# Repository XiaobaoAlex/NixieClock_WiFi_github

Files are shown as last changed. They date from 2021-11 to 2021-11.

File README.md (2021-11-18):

# NixieClock_WiFi
## 辉光管时钟

### 一、项目概述

&nbsp;&nbsp;&nbsp;&nbsp;&nbsp;&nbsp;&nbsp;&nbsp;功能简述：以飞思卡尔MC9S08DZ60为主控芯片，驱动六个辉光管分别显示时分秒或者年月日，带有wifi模块可以连接互联网正时。

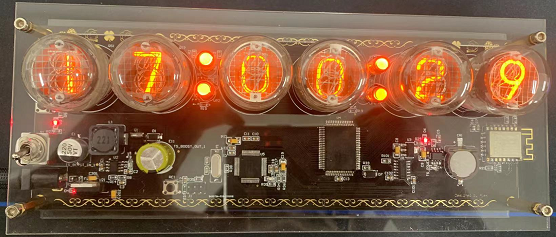
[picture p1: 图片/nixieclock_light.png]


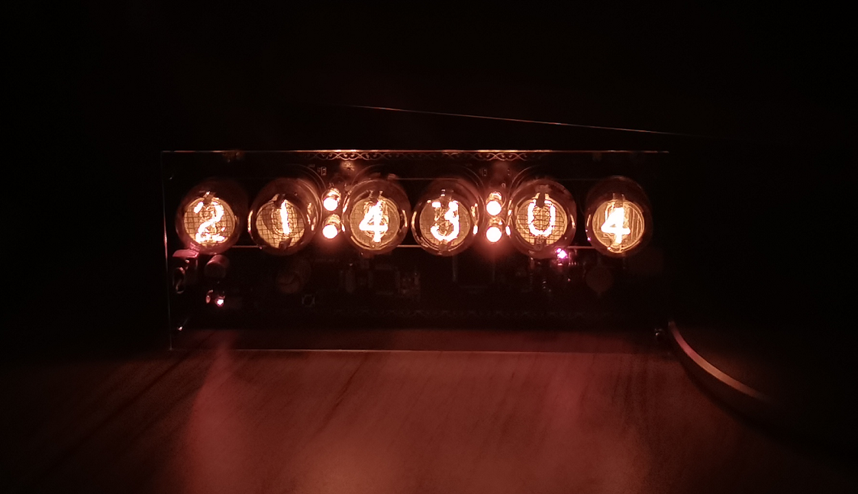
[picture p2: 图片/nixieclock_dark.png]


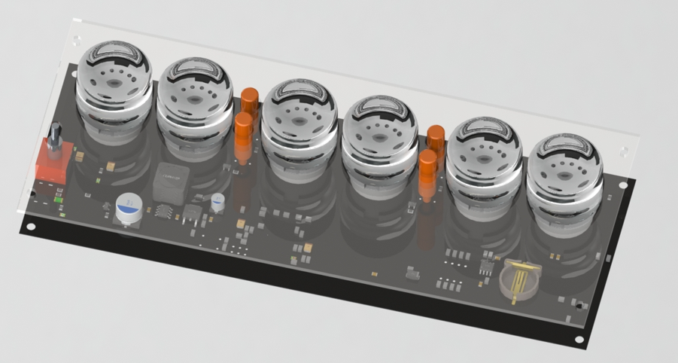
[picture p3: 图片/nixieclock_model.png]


### 二、实现思路

1.板子的最小系统以MC9S08DZ60为核心；

2.辉光管需要170V高压驱动，用MAX1771升压芯片做BOOST升压电路；

3.单片机IO口不足，不能同时控制6个辉光管的60个管脚，用HV57708PG 4路串行输入 64路并行输出芯片做辉光管驱动芯片；

4.使用DS3231实时时钟芯片计时；

5.使用ATK-ESP-01模块连接wifi接入互联网，利用sntp服务正时；

6.电源部分为12V输入，由boost电路将12V转换为170V供辉光管使用,用7805转换为5V作为板子主电源，ds3231和wifi模块的供电均为3.3v,需要电源转换芯片AMS1117-3.3做电源转换；

7.单片机供电电压和工作电压为5V,ds3231和wifi模块与单片机通信要做电平转换，3.3V和5V的电平转换由TXS0104EDR电平转换芯片完成；

8.显示部分由6个国产南昌牌顶显辉光管加4个作为间隔点的氖管组成。

### 三、具体实现

1、MC9S08DZ60最小系统

&nbsp;&nbsp;&nbsp;&nbsp;&nbsp;&nbsp;&nbsp;&nbsp;这个MC9S08DZ60是我们实验室用的芯片，之前也拿它做过毕设，软硬件都搞过，所以得心应手。但是到最后一版的时候，就是我用12V作为供电，用7805转5V给单片机供电之后，最小系统的晶振就是不起振，下不进程序，搞得我又去重新购置了一波元器件来更换最小系统上的电容和晶振，试了还不行。过了一段时间之后，我灵机一动，查了一下7805可不可直接给单片机供电，答案当然是可以，但是输入输出电容那部分就有讲究了。说是要加百uF级别的钽电容滤除低频干扰，nF级别的电容滤去高频干扰。我这按照数据手册上来画的，输出部分就加了100nF的电容，等我换上一个10uF的电容之后，最小系统就正常了。这个电容问题搞得我焊了好几个最小系统，还重新画了最小系统的晶振电路（重新打板），真磨人。

2、max1771升压芯片

&nbsp;&nbsp;&nbsp;&nbsp;&nbsp;&nbsp;&nbsp;&nbsp;关于这个芯片与升压电路真的有很多值得说的。这个电路的原理网上说的非常多，这里只说我设计与制作过程中的经验。

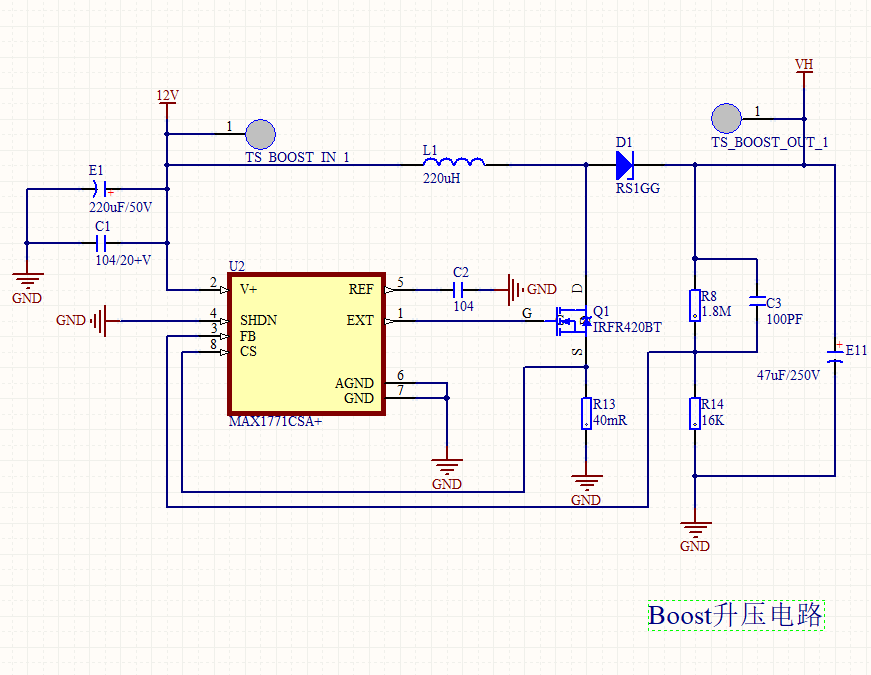
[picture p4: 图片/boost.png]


&nbsp;&nbsp;&nbsp;&nbsp;&nbsp;&nbsp;&nbsp;&nbsp;第一是元器件的选型，不能只想着各个元件的值对了就行，他们的功率也得跟上才行，换句话说他们都得足够大，耐压值大，功率大。这些大了体积自然就大了。我起初就是电感和电容的封装搞错了只能重新打板，当然这只是众多重新打板次数中的一次，E1的耐压值为50V,就是比12V的俩倍还要大，这样才安全。L1为功率电感，体积上去了功率就大，我选的是那种12x12的黑色立方体电感。E11为储能电容，输出电压为170V,所以耐压值得选250V.我选的是插针电解电容。还有就是MOS管Q1的耐压值也得大，要超过170V,我起初用的是数据手册上推荐的，但是我没注意到它是低压的mos管，结果电路不工作。D1得选快速开关的肖特基二极管。注意看的我这几个元件是不是都特别大，哈哈哈。

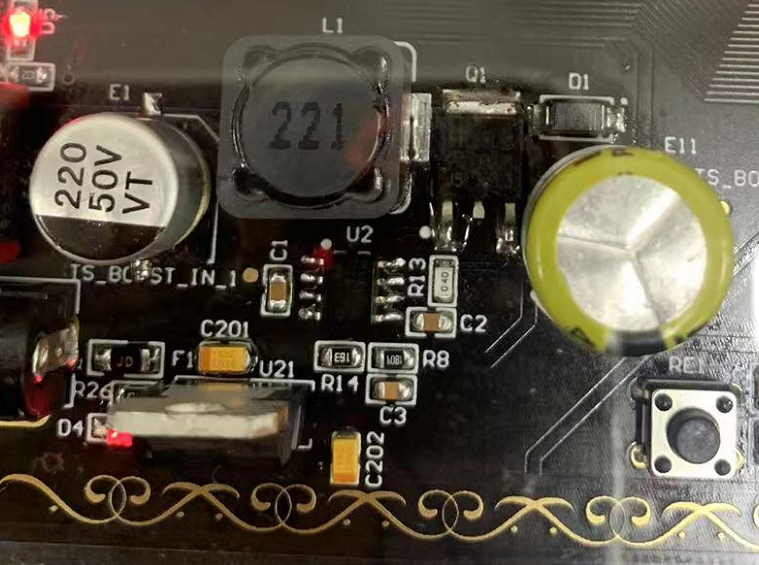
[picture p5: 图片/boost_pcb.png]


&nbsp;&nbsp;&nbsp;&nbsp;&nbsp;&nbsp;&nbsp;&nbsp;第二是升压部分。这个BOOST升压电路按我的理解就是开关电源，主要靠R8和R14来控制升压比，按数据手册上给的公式来看，理论上电压升到任何高度都可以，但是注意，电压肯定是不能升高到无穷大的，换句话说，我们要注意输入电压的大小。我们需要一个170V的高压辉光管才能正常工作，那我们应该用多大的电压作为输入呢。实践证明，5V是不行的，我起初是用5V做的输入电压，想着用type-c接口为板子供电，这样电路在空载的时候输出很不错，稳稳的170V,到这我就以为我的升压电路做好了，可是到最后同时驱动6个管子的时候，电压直线下降，加上6个管子之后升压电路输出只有122-125V,六个辉光管亮是亮了，但是缺笔画现象严重，有的管子甚至不亮，根本不能用。中间还以为我选的电感有问题，疯狂研究这个升压电路，最后换了那种5.5mm-12V圆形接口才成功（第二次打板）。网上虽然大多是用12V作为输入的，但是他们也没说5V不行啊啊啊啊。

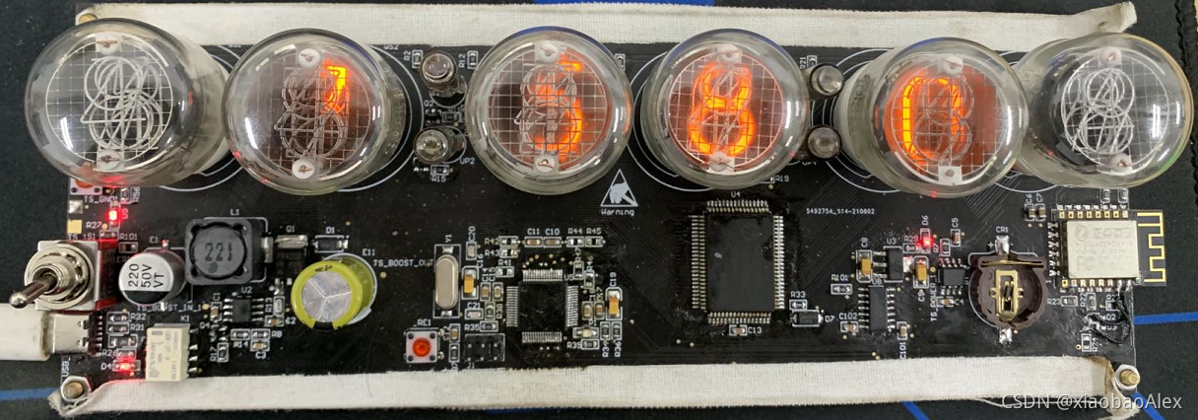
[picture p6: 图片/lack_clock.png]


3、ATK-ESP-01模块

硬件部分

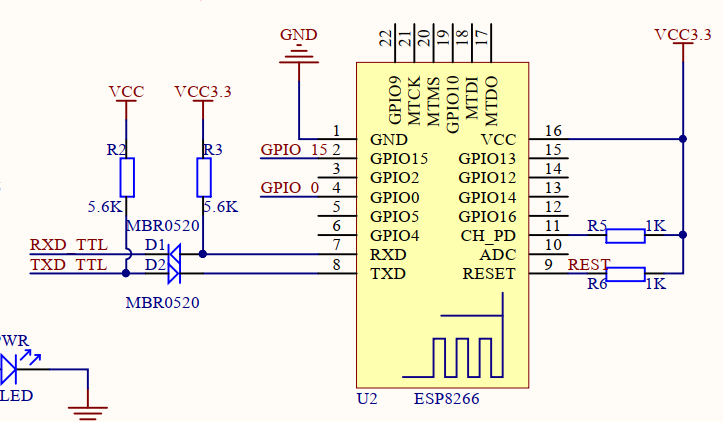
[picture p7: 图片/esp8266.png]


&nbsp;&nbsp;&nbsp;&nbsp;&nbsp;&nbsp;&nbsp;&nbsp;TX、RX需要和单片机叉接。它这个原理图就非常的まよい，这俩个上拉电阻和二极管给我整懵了，搞得我以为D1那条线是TX,D2那条线是RX.当然到最后我理解这个原理图的深意，其实他是对的。（当TXD输出1，二极管截至，TXD_TTL被拉高，也是1；当TXD输出0，二极管导通，TXD_TTL和TXD电平相等，也是0。）最后我是没要这俩个上拉电阻和二极管，直接连的电平转换芯片，它内部已经被上拉了的。

软件驱动部分

&nbsp;&nbsp;&nbsp;&nbsp;&nbsp;&nbsp;&nbsp;&nbsp;直接用AT指令驱动，需要注意的是，它的默认波特率为115200，需要操作一下把波特率改为9600方便后来操作；另外调试这个模块一定一定要搞串口调试器和逻辑分析仪，先用串口调试器和串口调试助手发送指令看看能不能连接无线网，测试模块的功能是否正常，之后用单片机收发指令的时候需要逻辑分析仪看所有信息的发送接收情况，这样你就能知道问题到底出在哪里。
在连上路由之后需要设置时区，注意，发送连接wifi指令之后大概4-5s模块才能真正连接路由，这个时候才能设置时区，所以在发送连接wifi命令后要设置比较长的延时，不然返回的时间就是1970年00时00分00秒。
那么接收时间字符串之后如何把时间信息取出。主要用memcpy和strstr函数解决，用memcpy函数将固定区域的字符串取出就可以得到年月日时分秒星期，对于月份和星期，他们是字母表示的，得用strstr函数判别，如果找到对应字符串就能确定是月份和星期。具体代码请查看我的开源项目链接，不拿出来说啦。

4、DS3231实时时钟芯片

&nbsp;&nbsp;&nbsp;&nbsp;&nbsp;&nbsp;&nbsp;&nbsp;DS3231是一款高精度I2C实时时钟器件，具有集成的温度补偿晶体振荡器。该器件包含电池输入端，断开主电源时仍可保持精确计时。集成的晶体振荡器可提高器件的长期精确度。芯片封装使用SOP-8封装，且几乎不需要外部器件支持，使用IIC协议和主控芯片通信。为了达到主要电路调电依旧可以完成走时的功能，使用3.7V CR1220 纽扣电池和电池座为DS3231MZ芯片提供备用电源，使芯片在外部供电中断时依旧可以走时。
这个软件驱动部分主要就是看网上的驱动代码，遇到问题就啃数据手册。

5、HV57708高压驱动芯片
这个芯片很有意思，起初我是没有看数据手册就是抄网上的驱动代码，结果发现驱动不了，就只得自己啃数据手册。

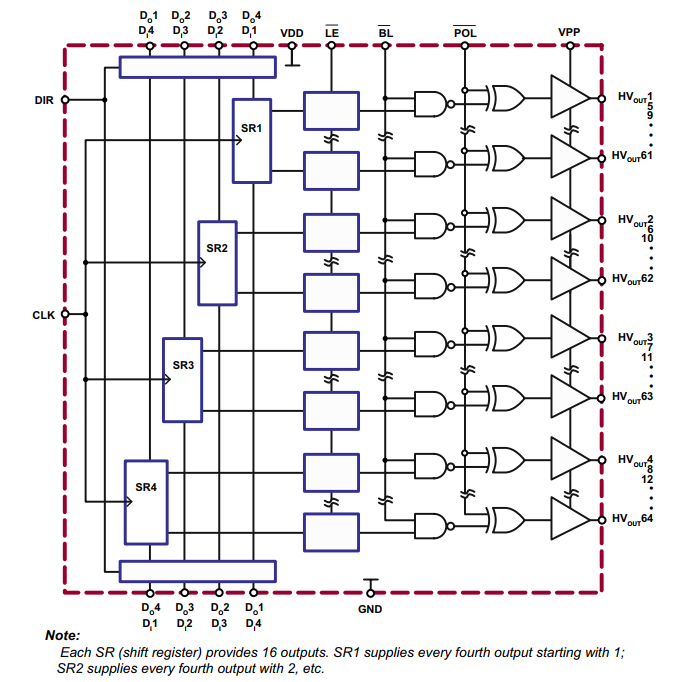
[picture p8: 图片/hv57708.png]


&nbsp;&nbsp;&nbsp;&nbsp;&nbsp;&nbsp;&nbsp;&nbsp;如上图所示，这里的POL是控制标准模式输出或反向模式输出的，驱动的辉光管亮灭的方法，是在所有数字阳极一个170V的高压，在某个数字阴极给68V，两端电压只有100多伏，电压不够该数字灭，反之给0V使数字亮。这种高电压灭低电压亮，就是反向输出模式。VPP上给68V电压，输出的高电压由此而来，它是靠稳压二极管把170V降压得来的.LE上有个取反符号，在写时序时要特别注意。
HV57708是一款可以承受高电压的串行输入转并行输出的驱动芯片，可完成4路输入转64路输出的功能。SR1、SR2、SR3、SR4都是16位寄存器，每个寄存器往右边控制16个管脚的高低压输出，他们加起来也就可以同时控制64个高低压输出。前提是要牺牲一定时间来写满这4个16位寄存器，那么如何写呢，我们注意看图，首先这四个寄存器与管脚不是一一对应的，如图SR1对应的管脚就是1、5、9、13…,这样设计主要是方便我们写入。要输入一个64位的值，这样的数据类型太大了，所以我们将其分开来放在俩个32位数据里，命名为datapart1、datapart2，首先按照Di4、Di3、Di2、Di1的顺序，将后一个32位的数据datapart2的后四位，写入这4个16位寄存器SR4、SR3、SR2、SR1的第一位值（从上面的Di4、Di3、Di2、Di1写，用DIR可以控制写入方向），也就是写好了64、63、62、61这个四个端口，看！这样是不是就正好对上了，我要输入数据的最后四位就对上了这个芯片的最后四位。之后依此类推，再次写入15次，这64位寄存器就全写好了，缺点就是牺牲了时间，但是这个芯片的时序非常快，大家不用担心，驱动秒级别的时钟根本没问题。当时看懂这个芯片还挺开心的，觉得非常有意思。真，不懂就得看数据手册，网上的信息很混乱，但是数据手册永远不会骗你。

6、辉光管与电路板总体布局

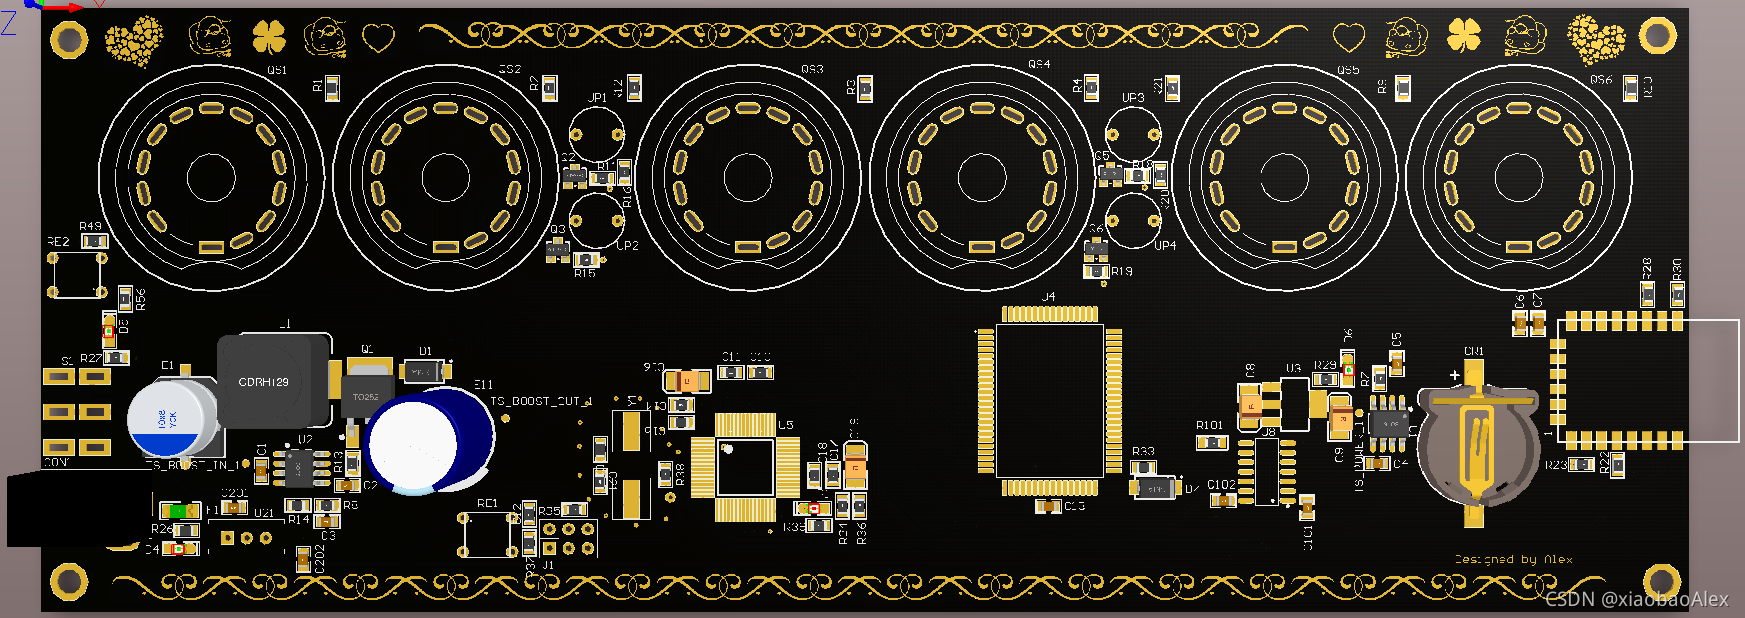
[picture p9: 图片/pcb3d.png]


&nbsp;&nbsp;&nbsp;&nbsp;&nbsp;&nbsp;&nbsp;&nbsp;六个辉光管分别显示时分秒，中间由氖管作为分隔符隔开。板子采用沉金工艺，上面的图案作装饰用 ，别忘了这是做给女朋友的礼物，哈哈哈。为了找这个花边的图案我花了好长时间，处理这个花边的时候因为画图自动的二值化效果太差了，我还用了matlab进行二值化，真的是走心的。

7、壳体

&nbsp;&nbsp;&nbsp;&nbsp;&nbsp;&nbsp;&nbsp;&nbsp;亚克力板1.9毫米无色高透明材质，CAD绘制好找淘宝加工，4块板11块钱，挺好不贵。

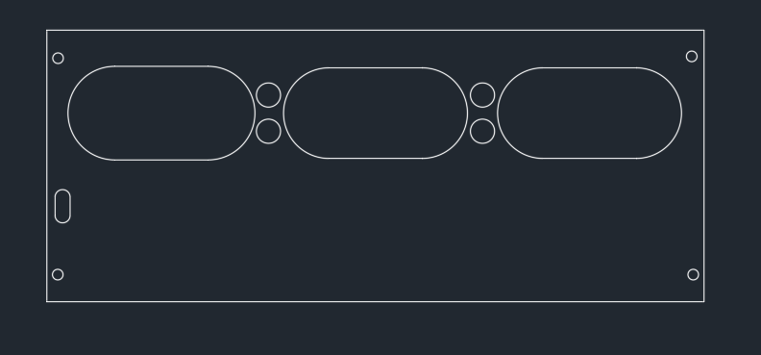
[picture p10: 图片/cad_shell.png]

9、软件架构

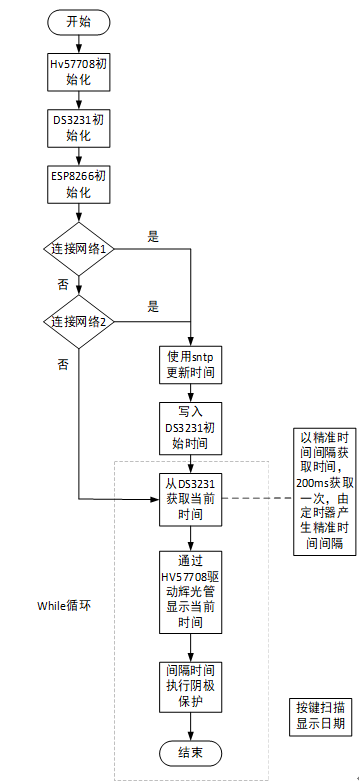
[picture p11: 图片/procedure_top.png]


### 四、总结与心得体会

&nbsp;&nbsp;&nbsp;&nbsp;&nbsp;&nbsp;&nbsp;&nbsp;这个项目最开始的电路原理图、电路板和程序搞的特别快，毕竟网上有很多资料可以参考，电路照着画再稍微根据自己的实际情况修改一下，程序拿别人的驱动再结合自己单片机修改一下，最初的电路板和程序搞的比较快，但是这时候电路板和程序都不知道好不好使，电路板只是自己认为没有问题，程序只是编译通过不报错。接下来就是漫长曲折的调试环节，中间遇到了各种问题，踩了很多坑，可以说该踩的坑都踩了。回想起来，前期绘制了3维模型并作了渲染，打板回来后就一直进行软硬件调试，遇到问题的时候请教了很多朋友，老师；各种论坛看各种帖子也请教了不少博主；下载了很多别人的项目来参考；使用各种调试工具来辅助调试；改了很多最初的设计，在嘉立创打了4次样板。可以说这是一个站在前人的肩膀上，不断思考不断尝试不断修正的过程，最终完成了这个项目。

&nbsp;&nbsp;&nbsp;&nbsp;&nbsp;&nbsp;&nbsp;&nbsp;好了，完结撒花。

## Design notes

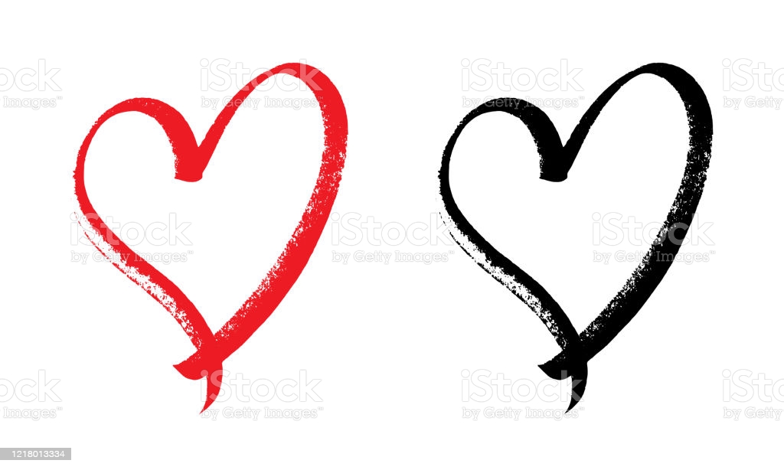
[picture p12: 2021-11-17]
图片/istockphoto-1218013334-1024x1024.jpg

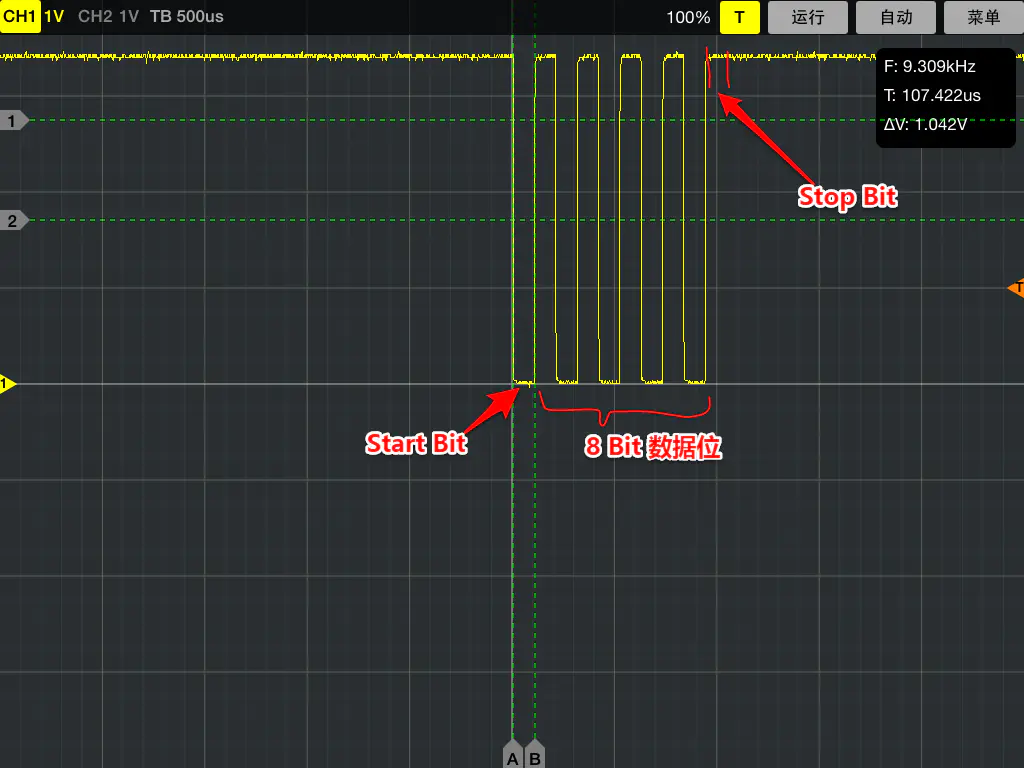
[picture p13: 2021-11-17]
图片/ee204bfbc8d77fdf14ca48ce8faf381a.png

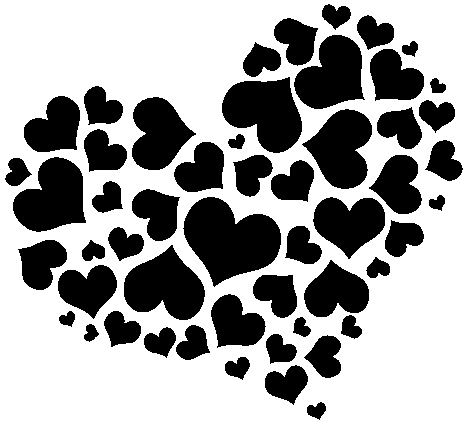
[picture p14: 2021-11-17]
图片/xinxin.bmp

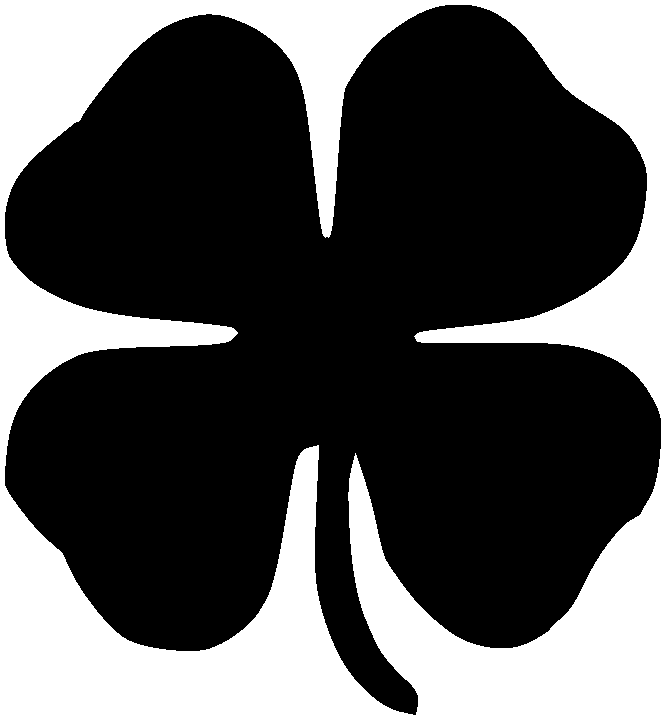
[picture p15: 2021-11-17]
图片/四叶草.bmp

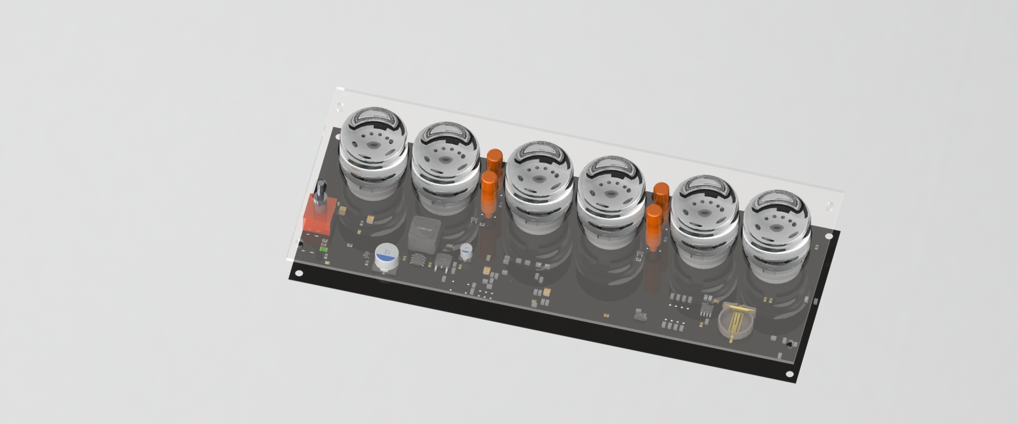
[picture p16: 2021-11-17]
亚克力面板/渲染效果图4.JPG

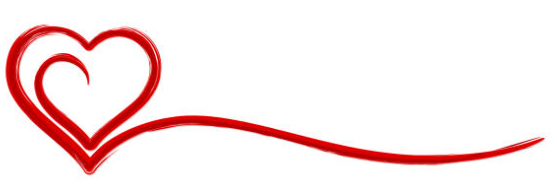
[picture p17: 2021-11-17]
图片/微信截图_20210717144555.png

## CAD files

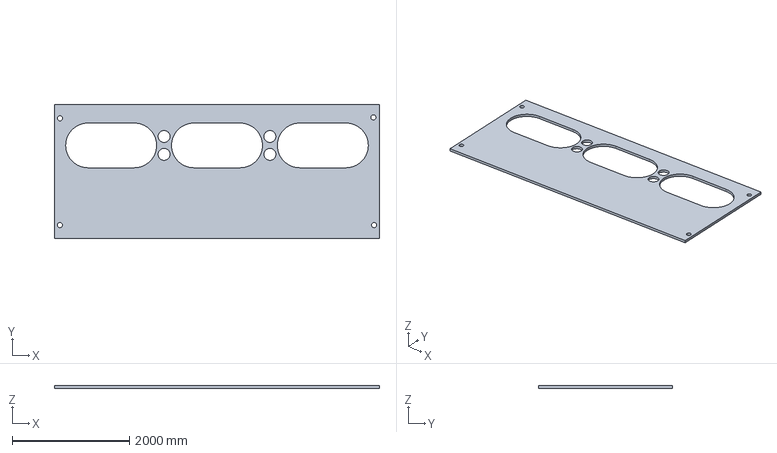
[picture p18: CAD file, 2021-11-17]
亚克力面板/step/top_panel4.stp
5537.2 x 2286.0 x 48.3 mm

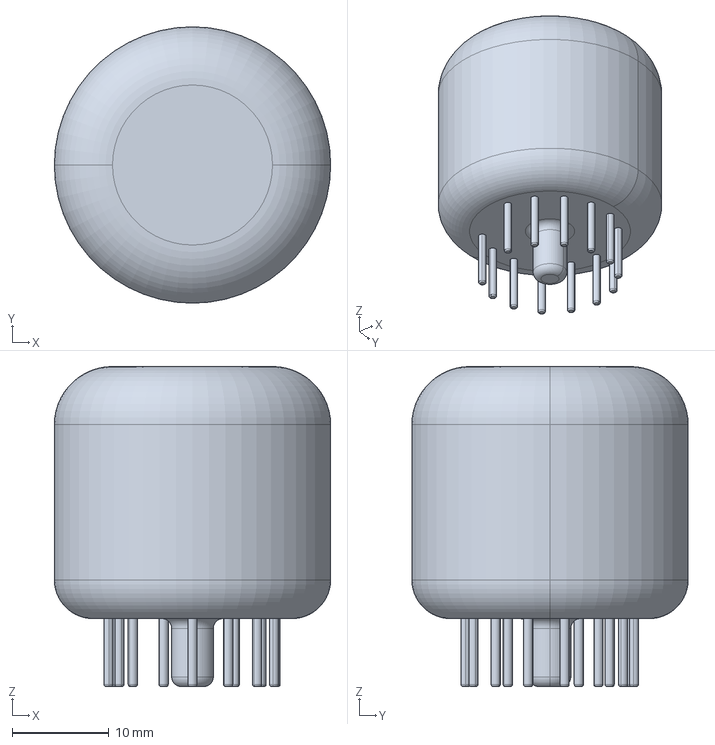
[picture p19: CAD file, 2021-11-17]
亚克力面板/step/nixie_tube.stp
28.5 x 28.5 x 33.0 mm

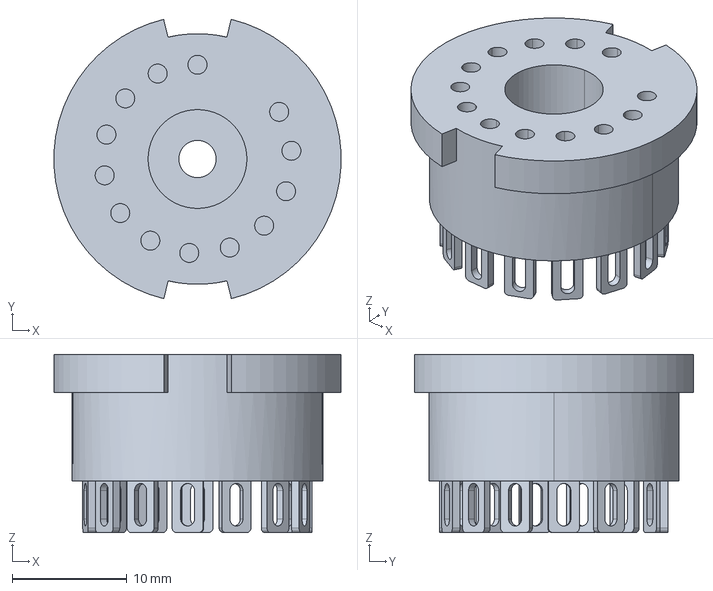
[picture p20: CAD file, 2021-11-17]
亚克力面板/step/tube_socket.stp
25.0 x 24.3 x 15.5 mm

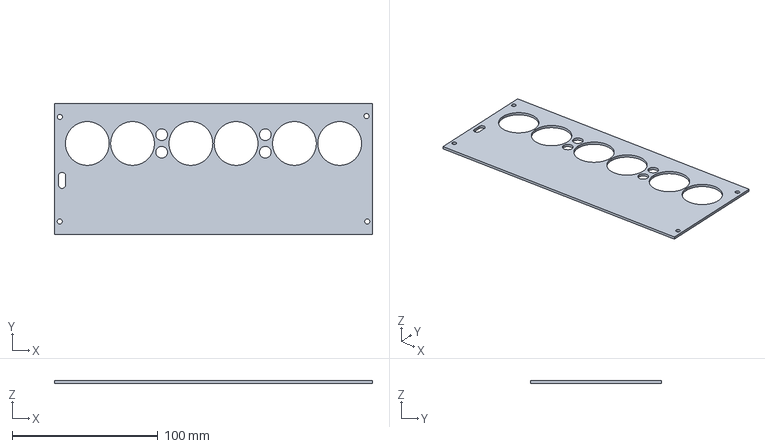
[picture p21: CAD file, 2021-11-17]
亚克力面板/step/top_panel3.stp
218.0 x 90.0 x 1.90 mm

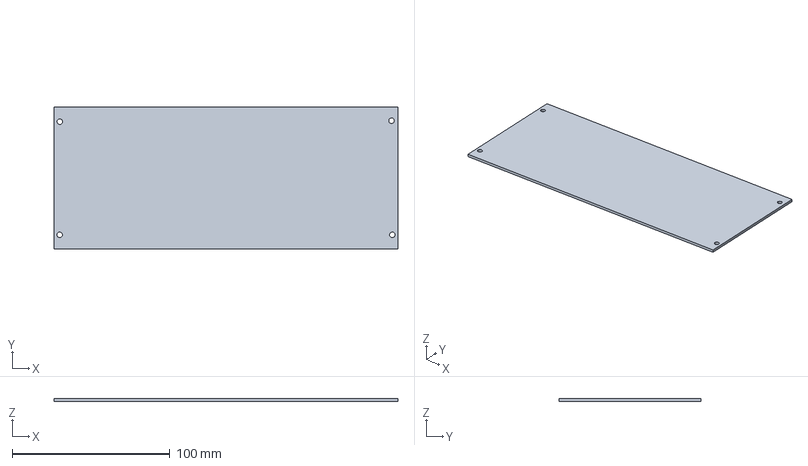
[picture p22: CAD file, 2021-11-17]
亚克力面板/step/bottom_panel.stp
218.0 x 90.0 x 1.90 mm

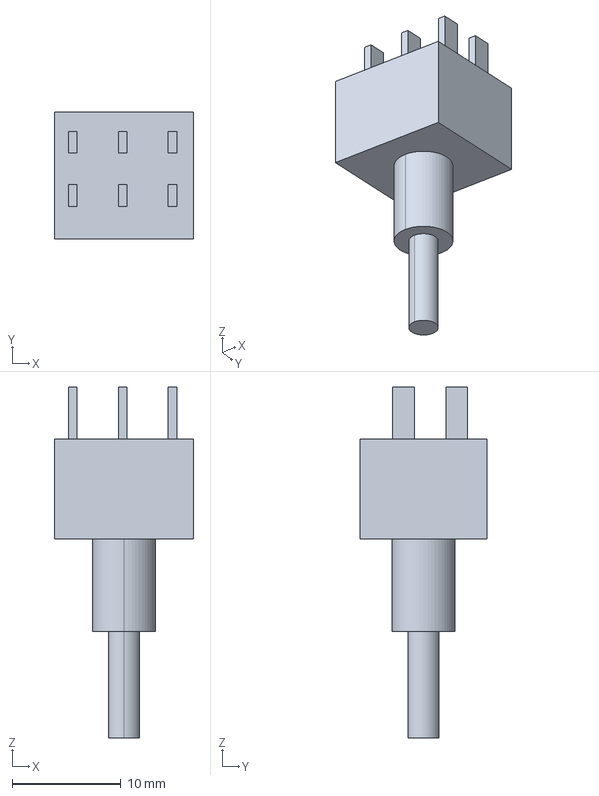
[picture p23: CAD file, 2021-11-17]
亚克力面板/step/toggle_switch.stp
12.8 x 11.7 x 32.4 mm

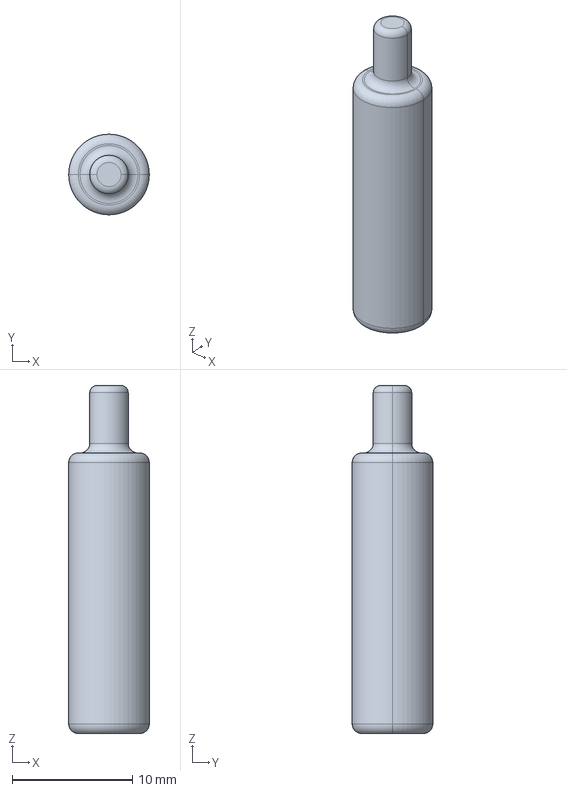
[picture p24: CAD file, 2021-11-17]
亚克力面板/step/neon.stp
6.70 x 6.70 x 28.9 mm

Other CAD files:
Hard_work/nixie_clock.DWG
亚克力面板/上面板第二版/top_panel.dwg
亚克力面板/dwg/bottom_panel.dwg
亚克力面板/dwg/top_panel.dwg

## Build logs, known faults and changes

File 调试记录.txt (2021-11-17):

先看资料

原理图已绘制完成

元器件已购买

pcb已初步布局

接下来进行精细布局，确定辉光管、氖管封装大小及位置，底板大小并建立三维模型，用solidworks绘制亚克力板模型

60x215较小，四周没有放置图案花纹的地方。打算扩大至75x230

电路板已发去打板

软件已编好

开始绘制3维模型

3维模型已画好

面板发去加工

升压电路焊接完毕，无法正常工作，查看数据手册发现mtd20N03hdl

mosDS之间的耐压值不够大，当初选这个是因为数据手册上的典型应用是这个，但是它那个是12V,5V低压输出，可以用这个低压mos管

试图更换MOS管IRFR420BTM

注重在制作过程中的拍照记录

贴片发光二极管有颜色的那一头为正

调试记录：

1、单片机是可以正常运行的，可使状态指示灯按照程序点亮熄灭

2、继电器应该是好使的，但闭合和断开时对应的升压电路的值为0和4.4V,考虑是继电器能通过的最大电流的值不够。

3、不应该是继电器能通过的最大电流的值不够这个原因。

4、辉光管驱动芯片VPP引脚处的稳压二极管稳压范围不够，已冒烟烧毁，可能是这个原因导致升压电路不能输出正常电压，寻找大电压范围的稳压管

5、经查数据手册和检查电路，发现稳压二极管焊反，而且稳压二极管的稳压值是对的，HV57708的VPP就是在90V之下。

6、稳压二极管调整之后稳压在70V,但是其他地方的170V也被稳在 了70V.

7、软件中，和esp8266进行串口通信存在问题，无法接收数据

8、单片机串口电平为5v,ESP8266串口电平为3.3V，二者不能直接相连。在网上看了许多解决办法，有的说兼容，有的说串联200欧电阻，有的说有三极管做个简单的转换电路，有的说用电平转换芯片，决定上电平转换芯片重新制版

9、esp8266的灯不是很亮

10、去点稳压管和限流电阻之后电压回到了170V,但是纹波很大

11、氖管的大圆筒接负极

12、画完板之后用串口调试助手试试wifi模块

~~13、升压电路准备俩个电容位焊接电容~~

14、留出方形焊盘电源输入接口供可调电源输入以显示消耗电流

15、升压电路注意布局

16、去掉拨码开关改加按键在左侧

17、更改RS1G封装、继电器封装、

18、3.3V降压芯片放在右边离芯片近处，给时钟和wifi芯片更好的供电

19、由于240k限流电阻的焊盘太小了，导致虚焊或者错位，又或者印制电路板的原因，电阻焊上之后阻值莫名的小，只有53欧，然后就导致升压电路提供电流能力不足，只能被拉到70V,至此问题已清晰明朗。

20、把升压电路输出电容换大电压会稳很多

21、把所有小规格焊盘全部替换掉。

22、下次生成gerber文件记得过孔盖油

23、焊完电源焊最小系统板，不然真的不知道最小系统板为什么不能正常运行

24、板子焊完后发现单片机不能下载进程序，硬件电路重焊过后还是不好使，目前不能找出原因

25、已重新焊了最小系统，测试了可以正常运行，打算在这个板子上继续焊接

26、稳压二极管俩端电压还是有问题，稳在了10V以内的电压，但是升压电路输出的电压正常，限流电阻测出的阻值极大，这可能是稳压不正常的原因

27、串口通信注意TX,RX不要接错

28、波特率不一致但接近可能也会出现通信不成功的情况，减小波特率并缩小两者波特率之差可能会成功

29、esp8266模块出现发送指令之后，先返回发送的指令字符然后在返回应答字符，已购买逻辑分析仪等待进行下一步试验。示波器虽然也能实现逻辑分析仪的功能但还是比较费劲

30、逻辑分析仪非常好用，已解决wifi模块问题，上述现象是wifi模块的回显模式造成的，关闭即可

31、hv57708驱动已编写完成并验证测试成功。编写驱动需充分理解数据手册，不然不能理解别人程序是意思，虽然能借鉴但肯定不能完全适配自己项目的情况

32、这些管子由于生产年限久远加上当年生产技术的关系，完美程度不高，常见的一个通病就是显示笔段不完全，尤其是在标准供电电压下，很多的南昌牌与宇宙牌的管子显示亮度很差，很多笔画多处显示不全，这个问题在最初开发的时候搞的非常头痛。后来经过实际测试，找到的解决方法也比较简单，那就是提高驱动电压与降低限流电阻。通过实际的测试发现，只要不是老化非常严重的管子，一般驱动电压提高到200～250V左右，限流电阻阻值降低２０％～３０％左右时，大部分的管子都可以确保正常的显示亮度。极个别的管子如果依旧有个别的字符显示不全，则可尝试进行活化修复处理。

33、换成2.2M欧电阻过后电压变成了122-125V之间

34、换成1.8M欧电阻过后电压加6个管子变成了122-125V之间

35、换成1.8M欧电阻过后电压加2个管子变成了147-148V之间

36、换成1.8M欧电阻过后电压加1个管子变成了160-164V之间

37、稳压管的电压容易在运行一段时间后变为4V

38、空载电流在80mA-140mA

39、加上一个管子电流在150到200mA

40、把电感值加大，换成330uH后加两个管子变成130V左右,还是不行（听师兄说带载能力不够应该换小感值）

41、准备重新制版，电源换成12V，5v稳压换7805，去掉继电器，去掉hv57708上拉电阻,去掉WiFi模块电阻和二极管，去掉usb,添加12v接口，过孔盖油



42、板子已改好发去嘉立创加工

43、板子已到准备焊接

44、新板电源纹波在159mV和239mV之间跳动，晶振不起振。

45、老板电源纹波和新版差不多，但是晶振起振，在晶振下方测量会出现良好正弦波形，频率为4Mhz

46、晶振两边的电压2.4V（正弦输出端）和1.1V，焊了最小系统，也不行。

47、换了2.2M欧的RF,晶振两边的电压3.0V（正弦输出端）和1.6V

48、第四版已发去加工，改进了晶振PCB布局

49、第四版最小系统已焊接，晶振俩端的电压为0.1v左右，正常的晶振俩端电压为2.2-2.3V.准备换一批元器件试试

50、已从电子大世界重新采购一批元器件，准备焊接测试

51、今天下午再焊一版试试，不行重新修改

52、下午焊的新版成功运行程序，在7805的输出端加了10uf的电容

53、弄清楚c语言双引号和单引号的区别，双引号会自动在字符串的末尾加上'\0'，单引号不会，而c语言函数库正是使用这个来判断该字符串是否结束，否则程序可能跑异常。

54、时钟初始化时向小时寄存器写0，导致时钟芯片在不连接互联网正时时小时位寄存器为0.

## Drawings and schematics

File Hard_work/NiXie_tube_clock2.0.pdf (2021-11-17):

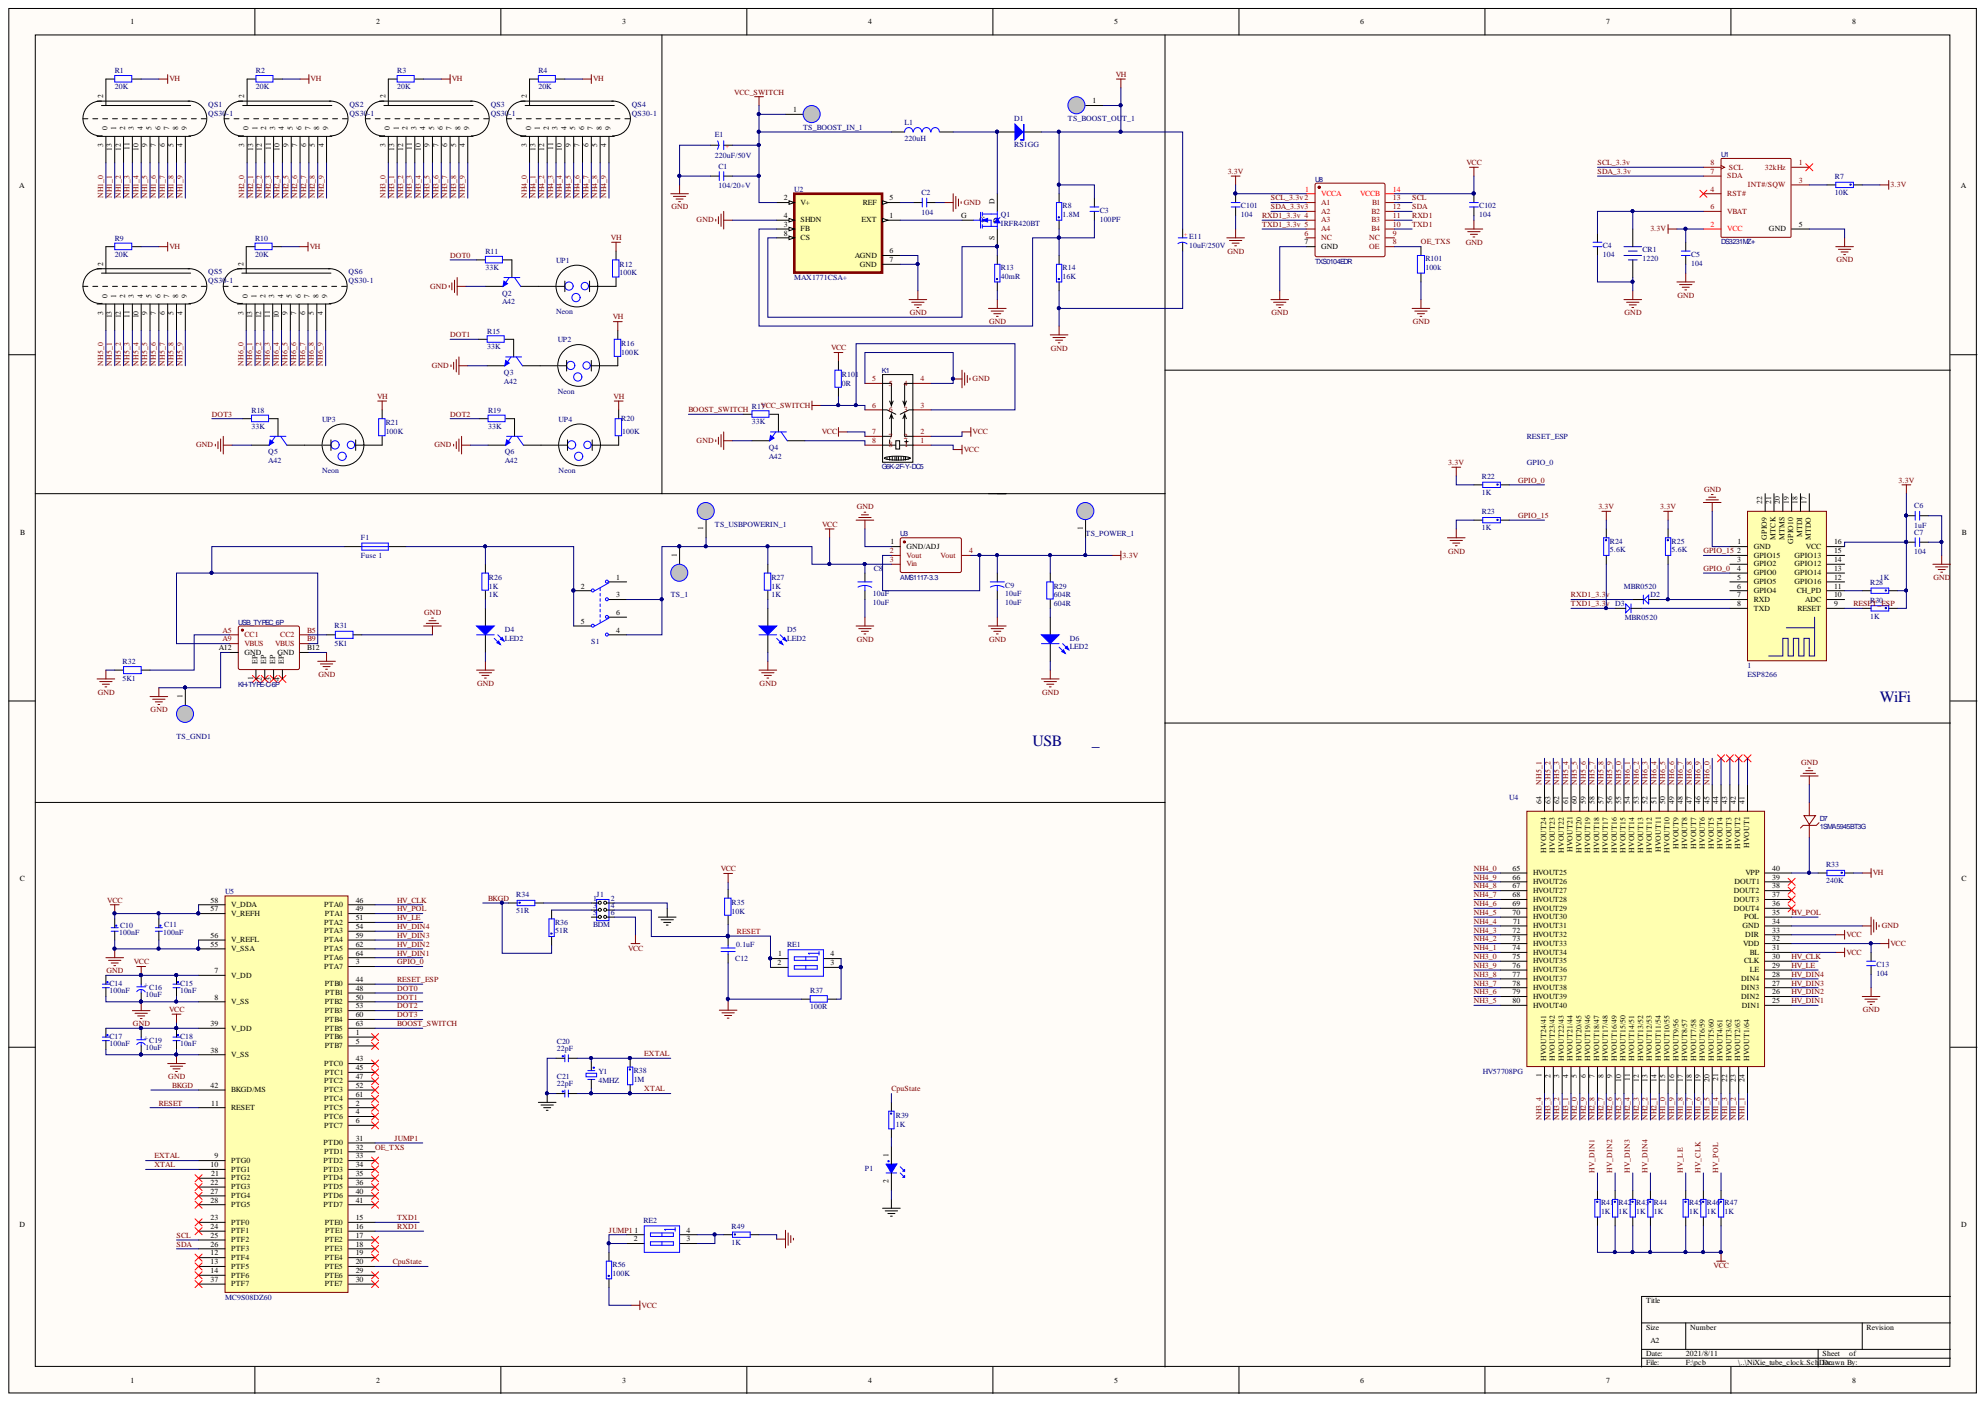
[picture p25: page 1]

HVOUT1/64 24 DIN1 25 DIN2 26 DIN3 27 DIN4 28 LE 29 CLK 30 BL 31 VDD 32 DIR 33 GND 34 POL 35 DOUT4 36 DOUT3 37 DOUT2 38 DOUT1 39 VPP 40

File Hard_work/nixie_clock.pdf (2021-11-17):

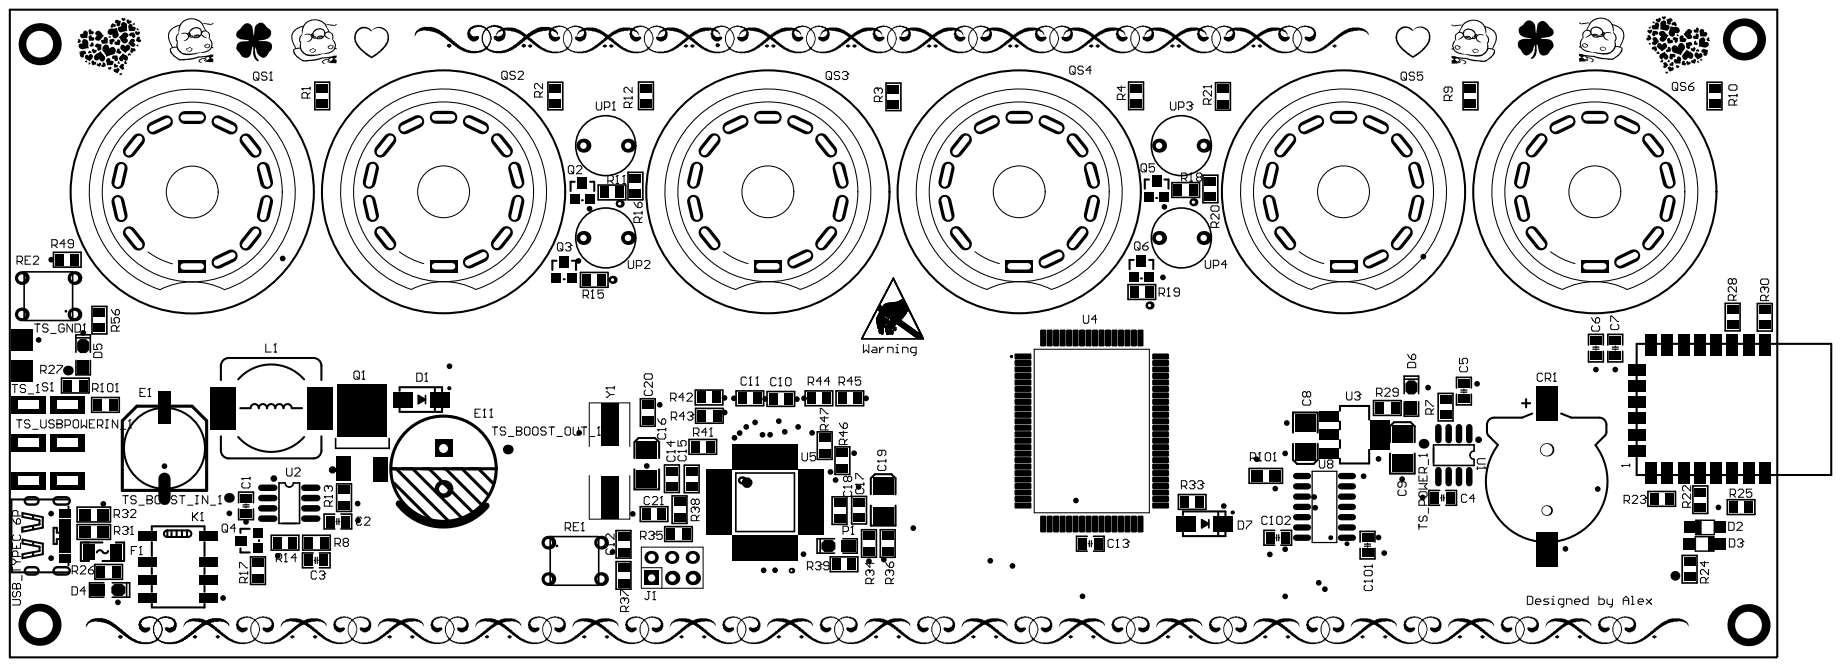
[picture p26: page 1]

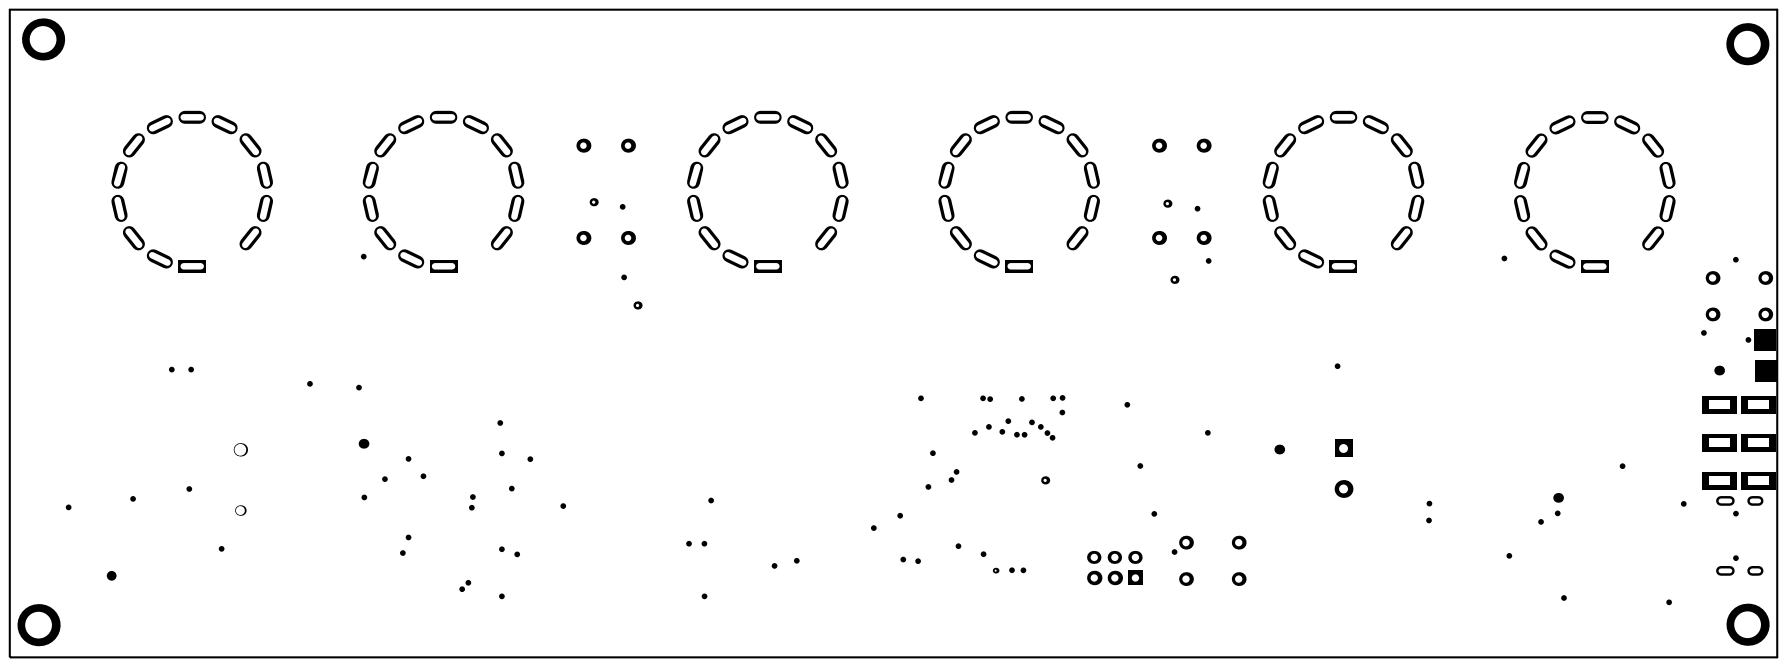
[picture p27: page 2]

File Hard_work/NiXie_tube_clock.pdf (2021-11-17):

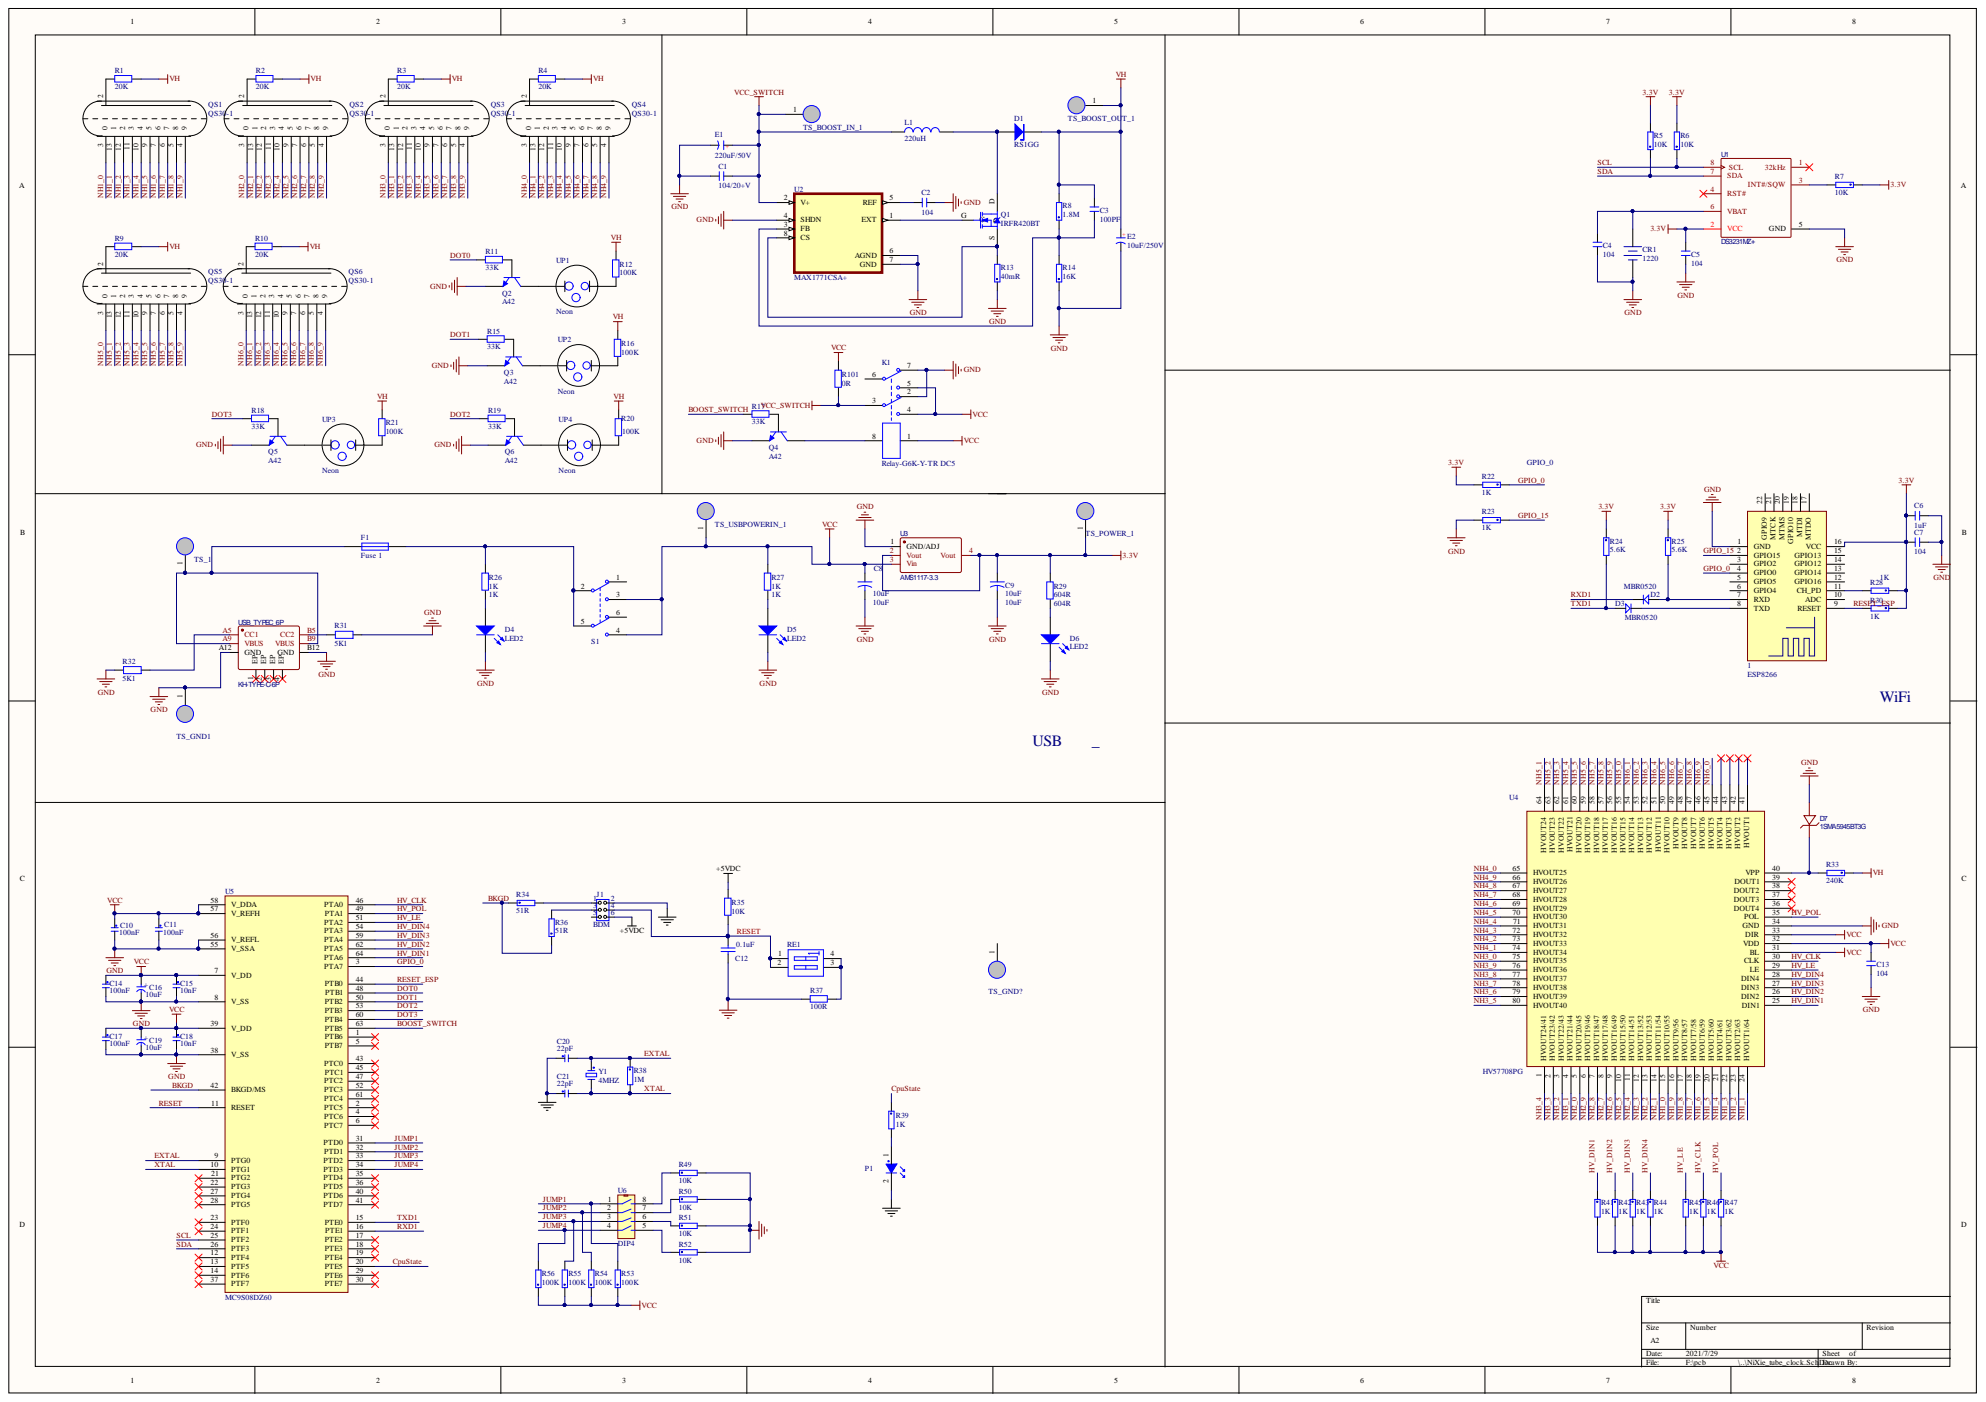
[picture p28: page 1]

MTDO 17 MTDI 18 GPIO10 19 MTMS 20 MTCK 21 GPIO9 22

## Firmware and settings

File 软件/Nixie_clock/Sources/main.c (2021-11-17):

#include <hidef.h> /* for EnableInterrupts macro */
#include "derivative.h" /* include peripheral declarations */
#include "HV57708.h"
#include "PinDef.h"
#include "delay.h"
#include "ds3231.h"
#include "esp8266.h"
#include "usart.h"
#include "stdio.h"
#include "string.h"


unsigned int Flag_Collect;//周期采集时间标志
#define RTC_1_MS        1
#define RTC_10_MS       10
#define RTC_100_MS      100
#define RTC_200_MS      200
#define RTC_1000_SEC    1000//RTC模数寄存器
#define LED	PTED_PTED5
#define LED_D	PTEDD_PTEDD5

struct time timearray;
unsigned char set[7]={0,0,0,0,0,0,0};
unsigned char cmd[4]={"AT\r\n"};//数组长度必须与实际指令字符长度一致
unsigned char close_echo[6]={"ATE0\r\n"};
unsigned char cmd_MODE[13]={"AT+CWMODE=1\r\n"};
unsigned char cmd_WIFI[29]={"AT+CWJAP=\"2205\",\"82568316+\"\r\n"};
unsigned char cmd_WIFI1[33]={"AT+CWJAP=\"CMCC-A35C\",\"6a3aJGbc\"\r\n"};
unsigned char cmd_TimeZone[36]={"AT+CIPSNTPCFG=1,8,\"ntp.aliyun.com\"\r\n"};
unsigned char cmd_Time[17]={"AT+CIPSNTPTIME?\r\n"};
unsigned char reback_Time[60]={'0','0','0','0','0','0','0','0','0','0',\
								'0','0','0','0','0','0','0','0','0','0',\
								'0','0','0','0','0','0','0','0','0','0',\
								'0','0','0','0','0','0','0','0','0','0',\
								'0','0','0','0','0','0','0','0','0','0',\
								'0','0','0','0','0','0','0','0','0','0'};
char reback_WIFI[20]={'0','0','0','0','0','0','0','0','0','0',\
'0','0','0','0','0','0','0','0','0','\0'};
char reback_WIFI1[20]={'0','0','0','0','0','0','0','0','0','0',\
'0','0','0','0','0','0','0','0','0','\0'};
unsigned char reback_WIFI_DISCONNECT[20]={'0','0','0','0','0','0','0','0','0','0',\
'0','0','0','0','0','0','0','0','0','0'};
unsigned char reback_WIFI_GOT_IP[20]={'0','0','0','0','0','0','0','0','0','0',\
'0','0','0','0','0','0','0','0','0','0'};
char result[14]={"CONNECTED"};
unsigned char result_dis[10]={"DISCONNECT"};
int flag1=0;
int flag2=0;
Bool flag=0;
char *ret;
char *ret1;
unsigned char State_Timing=0;
unsigned int Flag_Protect_count=0;//阴极保护显示计数
unsigned char CurrentT_all[7]={0,0,0,0,0,0,0};//用于存储从ds3231获取的完整时间信息
unsigned char CurrentT_time_array[6]={0,0,0,0,0,0};
const unsigned char sntp_time_data[7]={25,10,11,1,2,8,21};//用于存储通过sntp获取的完整的时间包括秒、分钟、时、星期、日、月、年
unsigned char reback[40]={"+CIPSNTPTIME:Mon Aug 02 11:10:25 2021"};



/*************************************************************/
/*                      初始化锁相环                         */
/*************************************************************/

void Init_PLL(void)
{


  /* disable COP */
  SOPT1 = SOPT1_STOPE_MASK;     /* disable COP, enable stop mode 禁用看门狗，使能停止模式*/

  /* Init Clock, Use PLL Engaged External mode, from 4MHz crystal -> 8 MHz bus初始化时钟，使用PEE模式，从4M外部晶振转到8M总线时钟 */  
  MCGC2 = MCGC2_RANGE_MASK|MCGC2_HGO_MASK|MCGC2_EREFS_MASK|MCGC2_ERCLKEN_MASK;
 		
  while (!MCGSC_OSCINIT);

  MCGC1 = MCGC1_CLKS1_MASK|MCGC1_RDIV2_MASK|MCGC1_RDIV1_MASK|MCGC1_RDIV0_MASK;
  while (MCGSC_IREFST);       
  while(MCGSC_CLKST != 0x02);
  
  MCGC1 = MCGC1_RDIV1_MASK|MCGC1_CLKS1_MASK;
  MCGC3 = MCGC3_PLLS_MASK|MCGC3_VDIV2_MASK;
  while(!MCGSC_PLLST);

 

  MCGC1 =MCGC1_RDIV1_MASK ;
  while(MCGSC_CLKST != 0x03);
  while (!MCGSC_LOCK); 

//此代码按dz60数据手册（2008版）示例程序编写
}
/*************************************************************/
/*                       初始化实时中断                      */
/*************************************************************/
 void Rtc_Init(void)
 {
     RTCSC = 0x18;            /*LPO clock,1 kHz低功率振荡器 ，此种模式产生计数器的计数周期为1ms，实时中断使能*/
     RTCMOD = RTC_200_MS;      /*default set to 200ms  */
     
 }

/*************************************************************/
/*                       开启升压电路                      */
/*************************************************************/
void BOOST_ON(void)
{
	
		PTBDD_PTBDD5=1;
		PTBD_PTBD5=0;
}
/*************************************************************/
/*                       关闭升压电路                      */
/*************************************************************/
void BOOST_OFF(void)
{
	
		PTBDD_PTBDD5=1;
		PTBD_PTBD5=1;
}
/*************************************************************/
/*                       氖管开启                      */
/*************************************************************/
void NEON_ON(void)
{
	
 NEON_DOT0_D=1; 
 NEON_DOT1_D=1; 
 NEON_DOT2_D=1;
 NEON_DOT3_D=1;  
 
 NEON_DOT0 = 1;
 NEON_DOT1 = 1; 
 NEON_DOT2 = 1; 
 NEON_DOT3 = 1; 
}
/*************************************************************/
/*                       按键驱动日期显示                      */
/*************************************************************/
void KEY_drive(void)
{
 JUMP1_D=0;	
 if(JUMP1==0)
 {
 	KEY_delay();
 	if(JUMP1==0)
 	{
 	    DS3231_ReadTime(CurrentT_all);
        CurrentT_time_array[0]=CurrentT_all[6]/10;
	    CurrentT_time_array[1]=CurrentT_all[6]%10;
	    CurrentT_time_array[2]=CurrentT_all[5]/10;
	    CurrentT_time_array[3]=CurrentT_all[5]%10;
	    CurrentT_time_array[4]=CurrentT_all[4]/10;
	    CurrentT_time_array[5]=CurrentT_all[4]%10;                     
        
 		HV57708_Display(CurrentT_time_array);
 		Delay();
    	Delay();
    	Delay();
    	Delay();
    	Delay();
    	Delay();
    	Delay();
    	Delay();
    	Delay();
    	Delay();	
 	}
 	
 }
}
/*************************************************************/
/*                       实时中断函数                        */
/*************************************************************/
void interrupt 25 RTI_inter(void)
{   
if(RTCSC_RTIF == 1)
    RTCSC_RTIF = 1;
    Flag_Collect=1;   //大约0.2s采集一次  
}
/*
#pragma CODE_SEG __NEAR_SEG NON_BANKED
interrupt void RTI_inter(void)
{
  if(RTCSC_RTIF == 1)
    RTCSC_RTIF = 1;
    Flag_Collect=1;   //大约0.2s采集一次
 
}
#pragma CODE_SEG DEFAULT

*/
int is_in( char *s,  char *c)
{
    int i=0,j=0,flag=-1;
    while(i<strlen(s) && j<strlen(c)){
        if(s[i]==c[j]){//如果字符相同则两个字符都增加
            i++;
            j++;
        }else{
            i=i-j+1; //主串字符回到比较最开始比较的后一个字符
            j=0;     //字串字符重新开始
        }
        if(j==strlen(c)){ //如果匹配成功
            flag=1;  //字串出现
            break;
        }
    }
    return flag;
}

Bool isCoincide(char *a, char *p)
{
	char *ptemp = p;
	while (*a != '\0')
	{
		if (*a == *p)
		{
			a++;
			p++;
		}
		else
		{
			a++;
			p = ptemp;
		}
		if (*p == '\0')
		{
			return 1;
		}
	}
	return 0;
}


void main(){                                             //定时采集DS3231时钟芯片时间信息，通过RS232串口打印


  	LED_D=1;
    LED=1;
    Init_PLL();//初始化锁相环，总线时钟为8M
    OETXS_D=1;
    OETXS=1;//使能电平转换芯片，高电平该芯片使能
    GPIO_0D=1;
    GPIO_0=1;
    RESET_ESPD=1;
    RESET_ESP=1;//配置wifi模块引脚
    INIT_IIC();//初始化iic
	DS3231_Initialization();//初始化DS3231
    Rtc_Init();//实时中断初始化
    HV57708_Init(HV57708_MODE_INVERTION);//初始化HV57708,所有管脚无输出，辉光管静默,反相输出
    BOOST_ON();//升压电路开启
    NEON_ON();//氖管点亮
    HV57708_Display(CurrentT_time_array);
    INIT_SCI();
    
    send_string(4,cmd);//发送AT指令，这里建议设置发送字符个数，不然这个字符串发送函数会在发完既定字符之后发一些奇怪的东西。
    delay();
    delay();
  	delay();
    delay();//0.167s，发送指令之后要一段延时等待回文
    
    send_string(6,close_echo);//关闭回显，这个不关闭的话rx会先显示发送的信息再显示回文
    delay();
    delay();
  	delay();
    delay();
 	
    send_string(13,cmd_MODE);//设置模式
    delay();
    delay();
  	delay();
    delay();


    send_string(33,cmd_WIFI1);
    delay();
    delay();
  	delay();
    delay();
    delay();
    delay();
  	delay();
    delay();//如果连接上，立即接收会先收到WIFI DISCONNECT,再收到WIFI CONNECTED,故延时接收，确保接收到WIFI CONNECTED
    //如果没连接上，延时接收会接收到FAI,这样也能进入下面的判断
    SCI_receiveN(16,reback_WIFI);//这里会一直等待接收，这个接收字符长度必须与实际接收字符长度一致

    ret = NULL;
    ret = strstr(reback_WIFI, result);
	if(ret == NULL)
	{
		send_string(29,cmd_WIFI);//4s后应答连上wifi
		Delay();
	    Delay();
	    Delay();
	    Delay();
	    Delay();
	    Delay();
	    Delay();
	    Delay();
	    SCI_receiveN(16,reback_WIFI1);	
	}
    Delay();
    Delay();
    Delay();
    Delay();
    Delay();
  	Delay();
    Delay();
    Delay();
    Delay();
  	Delay();
    Delay();
    Delay();
    Delay();
  	Delay();
    Delay();
    send_string(36,cmd_TimeZone);//设置时区，设置时区不能急，要等wifi连接路由后设置，所以前面有许多延时函数
    delay();
  	delay();
    delay(); 
    send_string(17,cmd_Time);//获取时间
    SCI_receiveN(43,reback_Time);//接收时间，这里会一直等待接收，这个接收字符长度必须与实际接收字符长度一致
    
    extract_time(reback_Time,&timearray);
    tran_3231set_array(&timearray, set);
    
    ret1 = NULL;
    ret1 = strstr(reback_WIFI1, result);
    if((ret!=NULL)|(ret1!=NULL))
    DS3231_SetTime(set);//将刚刚获取的时间信息写入DS3231
    delay();
    delay();
  	delay();
    delay();
     
    DS3231_ReadTime(CurrentT_all);                               //掉电检测操作，电源短路或者供电系统电量彻底消耗掉才有效 每次上电读取一次当前时间信息
    if(CurrentT_all[6] == 0x00){                                 //年份信息为0x00，芯片时间需要初始化
        DS3231_Initialization();                               //初始化时间时钟芯片DS3231
       	send_string(17,cmd_Time);//获取时间
    	SCI_receiveN(43,reback_Time);//接收时间，这里会一直等待接收，这个接收字符长度必须与实际接收字符长度一致
    	extract_time(reback_Time,&timearray);
    	tran_3231set_array(&timearray, set); 
    	if((ret!=NULL)|(ret1!=NULL))
    	DS3231_SetTime(set);//将刚刚获取的时间信息写入DS3231                               
    }


    while(1)
    {
        LED=1;
        delay();
        delay();
        LED=0;
        delay();
        delay();
        Flag_Protect_count++;
        if(Flag_Protect_count==150)
        {
          HV57708_Protection();
        }
        if(Flag_Protect_count==300)
        {
          HV57708_5201314();
          Flag_Protect_count=0;	
        }
    	KEY_drive();
        DS3231_ReadTime(CurrentT_all);
        CurrentT_time_array[0]=CurrentT_all[2]/10;
	    CurrentT_time_array[1]=CurrentT_all[2]%10;
	    CurrentT_time_array[2]=CurrentT_all[1]/10;
	    CurrentT_time_array[3]=CurrentT_all[1]%10;
	    CurrentT_time_array[4]=CurrentT_all[0]/10;
	    CurrentT_time_array[5]=CurrentT_all[0]%10;                     
        
 		HV57708_Display(CurrentT_time_array);                                                            
                       
        delay();
        delay();
        delay();
        delay();

              
        
    }
    
}
 

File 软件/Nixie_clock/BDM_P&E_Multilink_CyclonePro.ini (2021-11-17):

[Environment Variables]
GENPATH={Project}Sources;{Compiler}lib\hc08c\device\src;{Compiler}lib\hc08c\device\include;{Compiler}lib\hc08c\device\asm_include;{Compiler}lib\hc08c\src;{Compiler}lib\hc08c\include;{Compiler}lib\hc08c\lib
LIBPATH={Compiler}lib\hc08c\device\include;{Compiler}lib\hc08c\include
OBJPATH={Project}bin
TEXTPATH={Project}bin
ABSPATH={Project}bin

[HI-WAVE]
Target=HCS08ICDCYCLMULT
Layout=C_layout.hwl
LoadDialogOptions=RUNANDSTOPAFTERLOAD="main"
MainFrame=0,1,-1,-1,-1,-1,130,130,1570,889
TOOLBAR=57600 57601 32795 0 57635 57634 57637 0 57671 57669 0 32777 32776 32782 32780 32781 32778 0 32806
CPU=HCS08




[HCS08ICDCYCLMULT]
CURRENTDEVICE=9S08DZ60
CMDFILE0=CMDFILE STARTUP ON ".\cmd\BDM_P&E_Multilink_CyclonePro_startup.cmd"
CMDFILE1=CMDFILE RESET ON ".\cmd\BDM_P&E_Multilink_CyclonePro_reset.cmd"
CMDFILE2=CMDFILE PRELOAD ON ".\cmd\BDM_P&E_Multilink_CyclonePro_preload.cmd"
CMDFILE3=CMDFILE POSTLOAD ON ".\cmd\BDM_P&E_Multilink_CyclonePro_postload.cmd"
SHOWPROT=0
HCS08DBGMODULEADR=0x1810
DBG0=DBG GENERAL DISARM_ON PROTECT_OFF ANALYZE_ON STEPATRUN_ON
DBG1=DBG PREDEFINED SELECT 0
DBG2=DBG PREDEFINED DBGENGINE END STOP 0x0
DBG3=DBG USER 0x0 0x0
ISRDISABLEDSTEP=1








[PEDEBUG]
CURRENTDEVICE=9S08DZ60
CURRENTMODE=0
ASK_BEFORE_ERASING_FLASH=1
AUTO_SYNC=1




[DEVICE]
CHIPMODE=9S08DZ60

[9S08DZ60]
PROGRAMMING_ALGORITHM=0
DOTRIM=1
PRESERVE1_START=0
PRESERVE1_END=0
PRESERVE1_ACTIVE=0
PRESERVE2_START=0
PRESERVE2_END=0
PRESERVE2_ACTIVE=0
PRESERVE3_START=0
PRESERVE3_END=0
PRESERVE3_ACTIVE=0
PRESERVE_EEPROM=0
CUSTOM_TRIM=0
NGS_TRIM_OVERRIDE_REFERENCE_FREQUENCY=3125000
ALTERNATIVE_ALGORITHM_PATH=
ALTERNATIVE_ALGORITHM_CHECKBOX=0

[SETTINGS]
DEFAULT_SOURCE_PATH=C:\Program Files (x86)\Freescale\CodeWarrior for Microcontrollers V6.3\prog\P&E
MEMORYSTART1=0
MEMORYSTART2=0
MEMORYSTART3=0




[STARTUP12]
show_hstep_assembly_details=0

[STARTUP]
CPUTARGETTYPENAME=HCS08 Processor - Autodetect
IO_DELAY_SET=0
USE_CYCLONEPRO_RELAYS=1
CyclonePro_poweroffonexit=0
CyclonePro_currentvoltage=255
CyclonePro_PowerDownDelay=250
CyclonePro_PowerUpDelay=250
Multilink_PowerDownDelay=250
Multilink_PowerUpDelay=1000
IO_DELAY_CNT=9
FREQ_FX=4
FREQ_NORMAL=0
FREQ_OSJTAG=0
FREQ_CYCLONE=3
FREQ_TRACELINK=3
FREQ_LIGHTNING=1
FREQ_OPENSDA=0
RESET_DELAY=0
PORT=21
PORT_NAME_STRING=
interface_selection=1
SHOWDIALOG=1

[HCS08]
FILE1=
BINTORAM=1
BINTOFLASH=0
BINTOFLASHDEFAULT=0
GOTILMAIN=0
KEEPCPROGOPEN=0

[SAVESETTINGS]
S19FILENAME=
PRGFILENAME=
PRGFILEPATH=C:\Program Files (x86)\Freescale\CodeWarrior for Microcontrollers V6.3\prog\P&E
SERIALFILENAME=

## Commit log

2021-11-17 上传至github
    [DS3231MZ+.SCHLIB, G6K-2F-Y-DC5.PcbLib, G6K-2F-Y-DC5.SCHLIB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]
2021-11-18 上传图片
